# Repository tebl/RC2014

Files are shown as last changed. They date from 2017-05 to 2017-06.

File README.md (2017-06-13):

# RC2014

I've been spending a lot of time lately working on extensions to the excellent RC2014 machine, check out the official web page at [http://rc2014.co.uk](http://rc2014.co.uk) if you're not familiar with it. Short story; it's a Z80-based homecomputer that you can build yourself using a soldering iron, lots of time and severely burned fingers. A lot of fun indeed!

I've been documenting the build process of the various components on my blog at [https://hvetebolle.blogspot.no/p/rc2014.html](https://hvetebolle.blogspot.no/p/rc2014.html), but take note that it's in my native language of Norwegian so it might not register as readable for most people.

## Modules

I'll be making a subfolder for each of the modules I've been working on, most of the files will be in KiCad format so you'll need this open source application installed if you intend to work with the schematics. For the most part I will include the necessary Gerber files (for PCB production) in each modules export folder, the schematic in PDF-format will also probably be included - also, in the export folder.

* [RC2014 IDE ATA adapter](https://github.com/tebl/RC2014/tree/master/RC2014%20IDE)
* [RC2014 Pageable RAM](https://github.com/tebl/RC2014/tree/master/RC2014%20RAM)
* [RC2014 Tandy Sound Card](https://github.com/tebl/RC2014/tree/master/RC2014%20Tandy%20Sound%20Card)

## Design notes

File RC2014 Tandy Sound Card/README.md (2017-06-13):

# RC2014 Tandy Sound Card

This is a sound card for the RC2014 that I've been tinkering with, it's based on the SN76489N chip so it should be something akin to the original Tandy Sound Card. Not that I actually had one of those mind you, I was lucky enough to have a computer in the early 90s and that was years before I managed to get a hold of my first used sound card (Creative Soundblaster 8-bit). Anyways, I digress...

# Schematic
The supplied KiCad files should be sufficient as both a schematic and as a starting point for ordering PCBs (basically you could just zip the contents of the export folder and upload that on a fabrication site), the schematic is also available in [PDF-format](https://github.com/tebl/RC2014/raw/master/RC2014%20Tandy%20Sound%20Card/export/RC2014%20Tandy%20Sound%20Card.pdf) so that you can refer to it while troubleshooting bad solder joints.

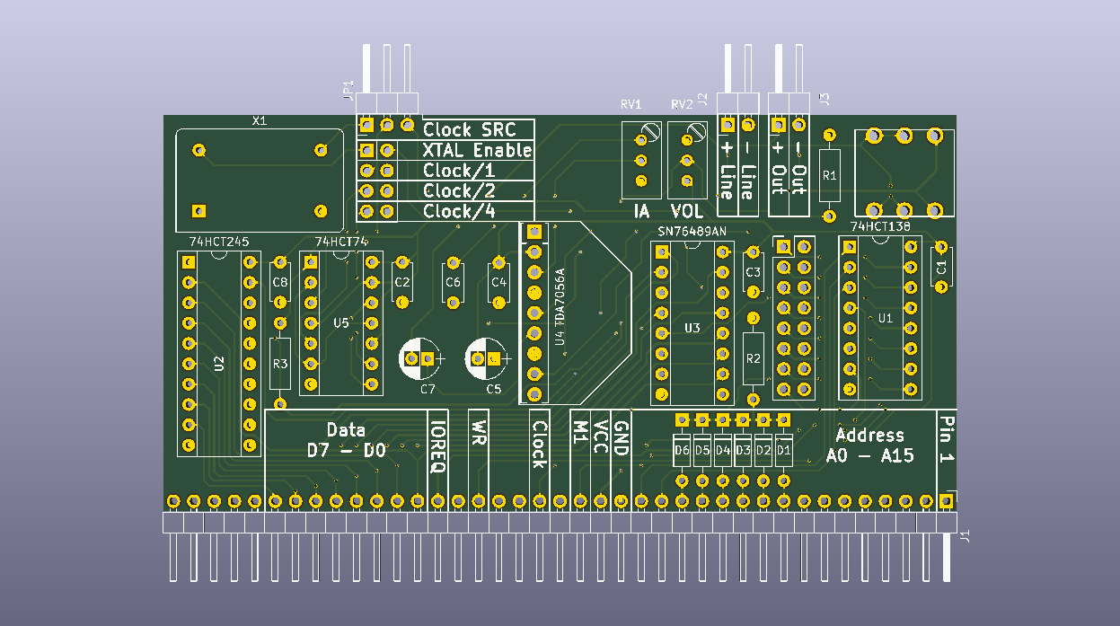
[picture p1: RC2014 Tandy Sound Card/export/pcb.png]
PCB Preview


# BOM
This is the part list as it stands now, having not yet received nor assembled the first version of this card so some changes will probably happen. Note that since this includes a lot of circuitry dealing with amplifying the signal, some parts of this may be left out if they are not needed. Jack socket may be omitted if you only want to attach a simple speaker to it using the one of the two speaker outputs J2 and J3 (with amplification). Crystal may be omitted, instead you can use the system clock with the clock divider to get this below SN76489AN max frequency (4 Mhz) - with a stock RC2014 you would atleast need to set J6 to divide it in half.

| Reference | Item | Count |
| --- | --- | ----- |
| PCB | Fabricate yourself using Gerber files | 1 |
| U1 | 74HCT138 DIP | 1 |
| U2 | 74HCT245 DIP | 1 |
| U3 | SN76489AN DIP | 1 |
| U4 | TDA7056A SIP (mono amplifier) | 1 |
| U5 | 74HCT74 DIP | 1 |
| RV1 - RV2 | Adjustable resistor, 10k | 2 |
| R1 | 1k resistor | 1 |
| R2, R3 | 10k resistor | 2 |
| X1 | TTL Oscillator, full can (DIP 14) | 1 |
| C1-C4, C8 | 100nF ceramic capacitor | 1 |
| C5 | 220uF electrolytic capacitor | 1 |
| C6 | 470nF ceramic capacitor | 1 |
| C7 | 470uF electrolytic capacitor | 1 |
| J1 | Single row, 39p right angle connector | 1 |
| J2, J3 | Single row, 2p right angle connector  | 2 |
| J4 | Dual row, 2x08 connector | 1 |
| J5 | FCR1295 3.5mm Jack Socket | 1 |
| J6 | Dual row, 2x04 connector | 1 |
| D1 - D6 | 1N4848 diode | 6 |

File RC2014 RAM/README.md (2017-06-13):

# RC2014 RAM

This is a customized RAM module that enables you to page the module in and out, similar to the 64K module available. The difference here is that I'm only using one RAM chip per card. The reason for this is simple, PCB manufacturers don't seem to want to make a single PCB so this way I can use more of them at once!

The PCB places the paging pin on one of the spare pins of the backplane, that way I don't have to run any wires between the cards.

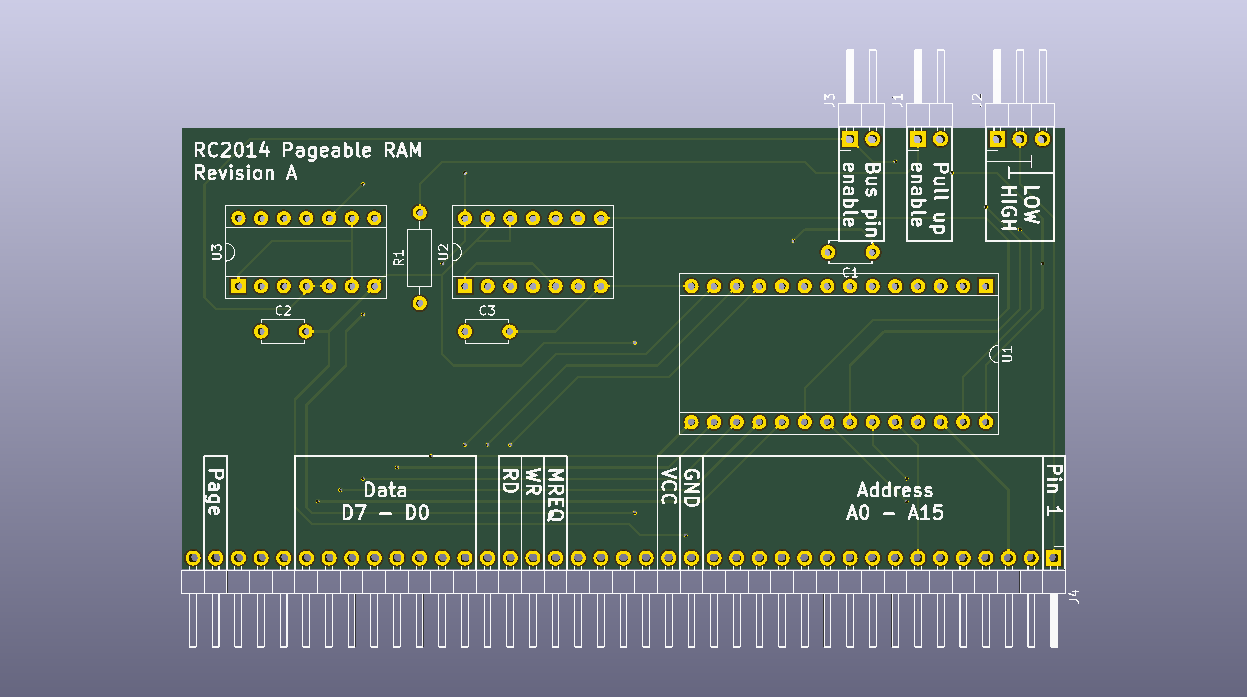
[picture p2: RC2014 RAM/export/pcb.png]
RAM PCB


# Schematic
The supplied KiCad files should be sufficient as both a schematic and as a starting point for ordering PCBs (basically you could just zip the contents of the export folder and upload that on a fabrication site), the schematic is also available in [PDF-format](https://github.com/tebl/RC2014/raw/master/RC2014%20RAM/export/RC2014%20RAM.pdf) so that you can refer to it while troubleshooting bad solder joints.

# BOM
| Reference | Item | Count |
| --- | --- | ----- |
| PCB | Fabricate yourself using Gerber files | 1 |
| U1 | 62256 32k * bit Static RAM | 1 |
| U2 | 74HCT32 DIP | 1 |
| U3 | 74HCT00 DIP | 1 |
| J2 | Single row, 3p right angle connector  | 1 |
| J1, J3 | Single row, 2p right angle connector  | 2 |
| J4 | Single row, 39p right angle connector | 1 |
| C1 - C3 | Ceramic capacitor, disc 100nF | 3 |

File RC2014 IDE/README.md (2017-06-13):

# RC2014 IDE ATA adapter

This is an IDE ATA adapter I've been working so that I can avoid having to learn how to solder surface mount components like the one used on the officialy available Compact Flash module. This gives you a standard ATA IDE connector that you can use for anything that still supports 8-bit IDE, where this relates to the Compact Flash module is that you can use it to connect up to a cheap Compact Flash to IDE adapter. See Scripts for a sample Basic-script that can be used to test the adapter.

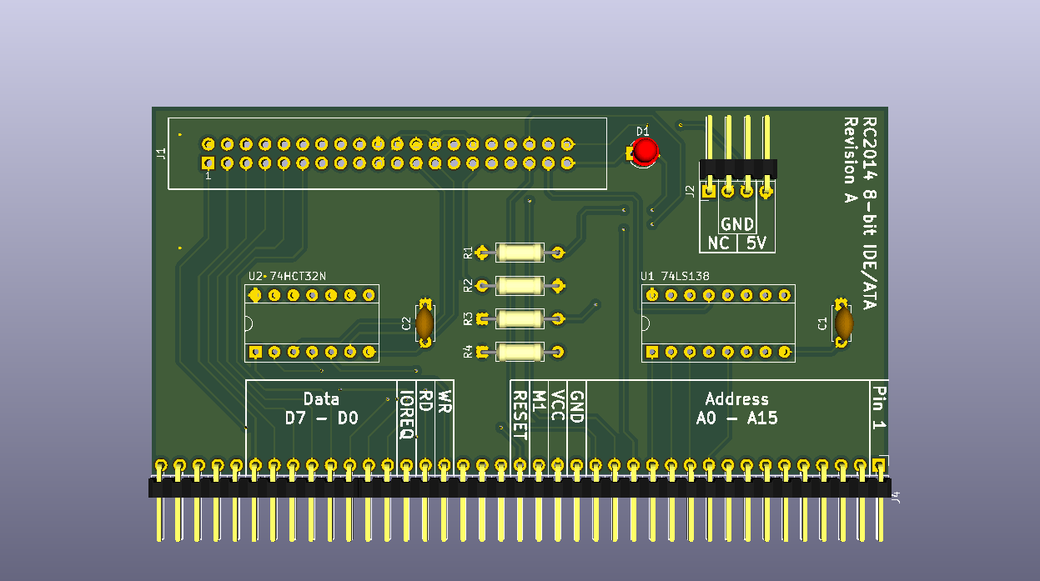
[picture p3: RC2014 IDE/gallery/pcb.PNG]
IDE PCB


Wired up

# Schematic
The supplied KiCad files should be sufficient as both a schematic and as a starting point for ordering PCBs (basically you could just zip the contents of the export folder and upload that on a fabrication site), the schematic is also available in [PDF-format](https://github.com/tebl/RC2014/raw/master/RC2014%20IDE/export/RC2014%20IDE.pdf) so that you can refer to it while troubleshooting bad solder joints.

# BOM
| Reference | Item | Count |
| --- | --- | ----- |
| PCB | Fabricate yourself using Gerber files | 1 |
| R1 - R3 | 1k resistor | 3 |
| R4 | 330 resistor | 1 |
| J1 | Dual row, 20p right angle connector | 1 |
| J2 | Single row, 4p right angle connector  | 1 |
| J4 | Single row, 39p right angle connector | 1 |
| C1 | Ceramic capacitor, disc 100nF | 1 |
| | 40 pin IDE cable (gray type) | 1 |
| | CF to IDE ATA adapter | 1 |

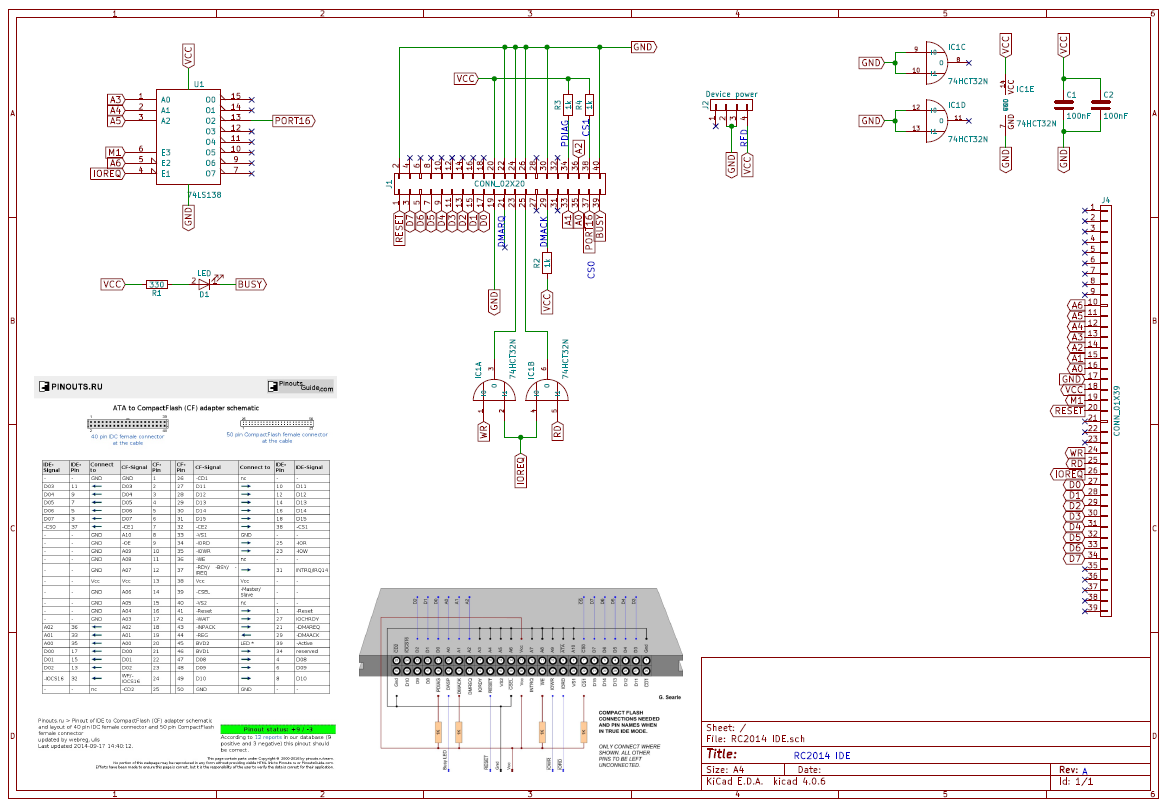
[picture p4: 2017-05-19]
RC2014 IDE/gallery/schematic (updated).PNG

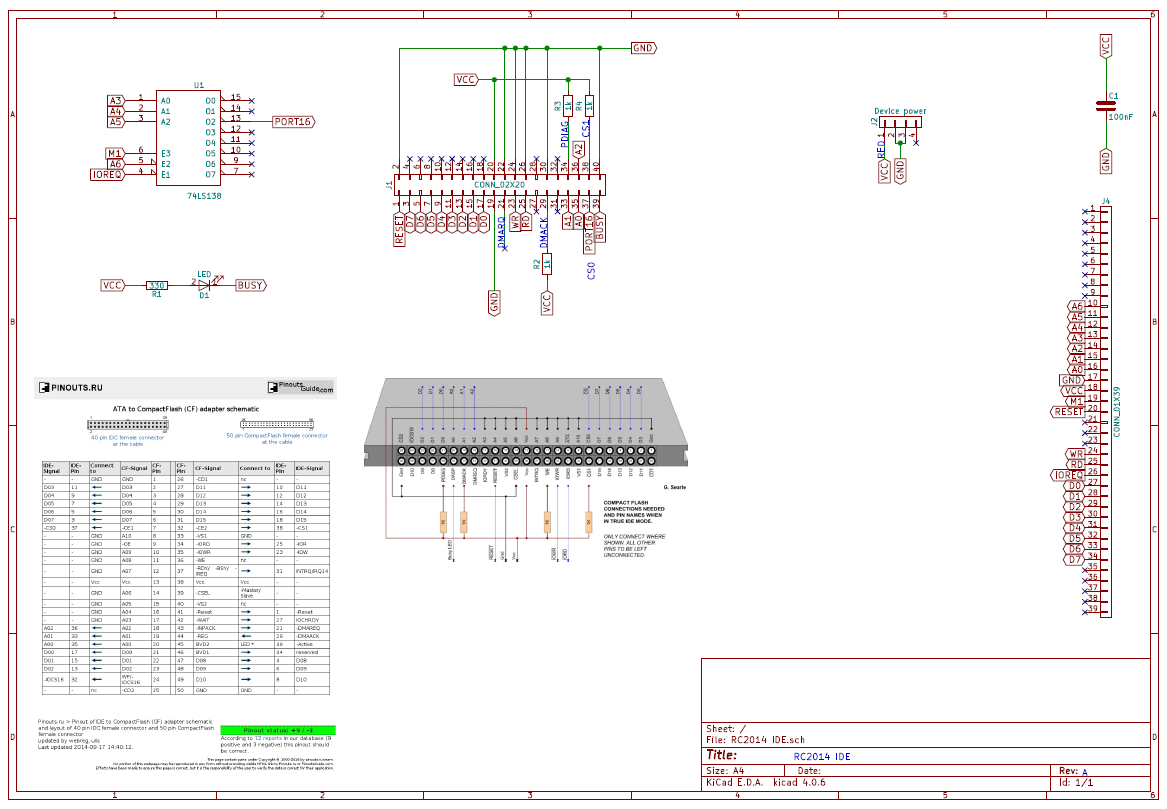
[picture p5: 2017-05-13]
RC2014 IDE/gallery/schematic.PNG

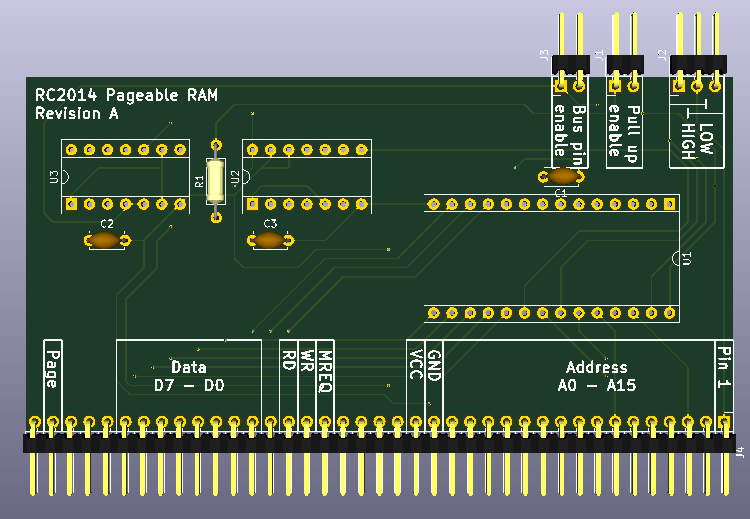
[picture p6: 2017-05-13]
RC2014 RAM/gallery/pcb.PNG

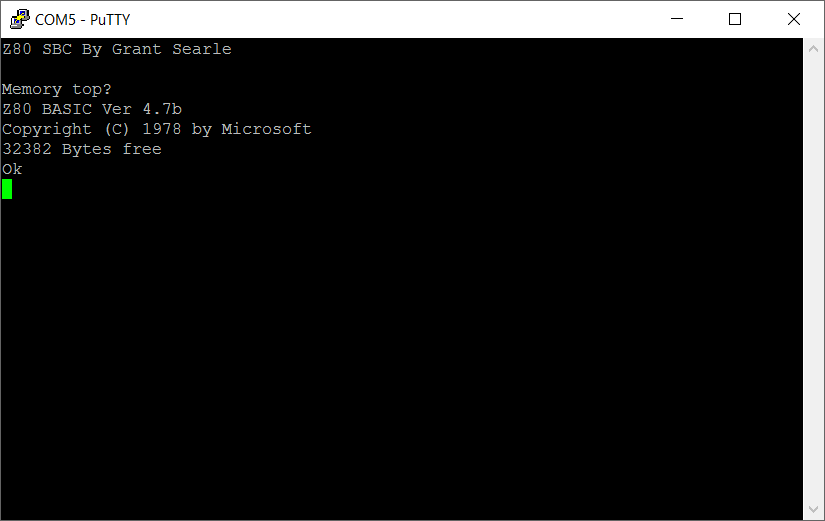
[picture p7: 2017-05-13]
Gallery/rc2014_ok.PNG

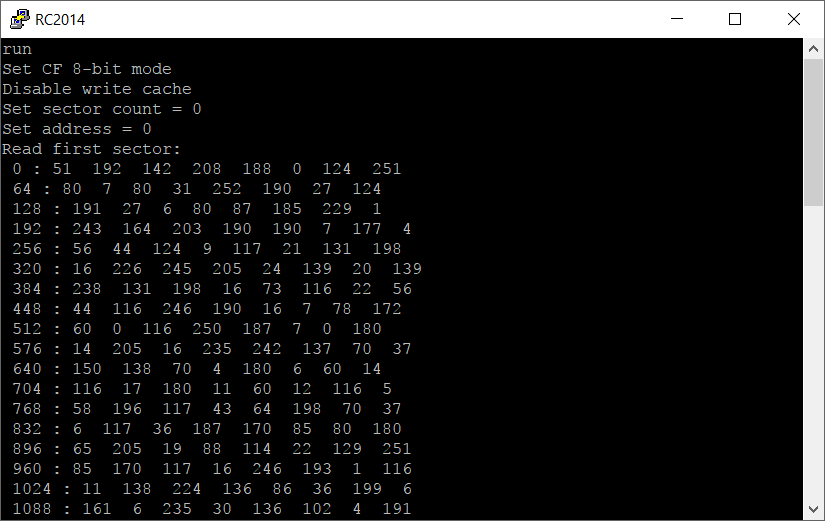
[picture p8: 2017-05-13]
RC2014 IDE/gallery/CF Sandisk Basic.PNG

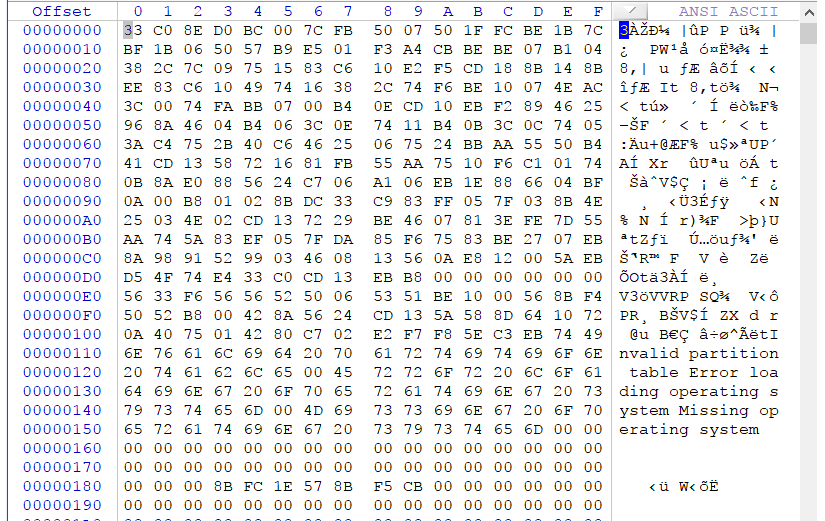
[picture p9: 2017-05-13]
RC2014 IDE/gallery/CF Sandisk.PNG

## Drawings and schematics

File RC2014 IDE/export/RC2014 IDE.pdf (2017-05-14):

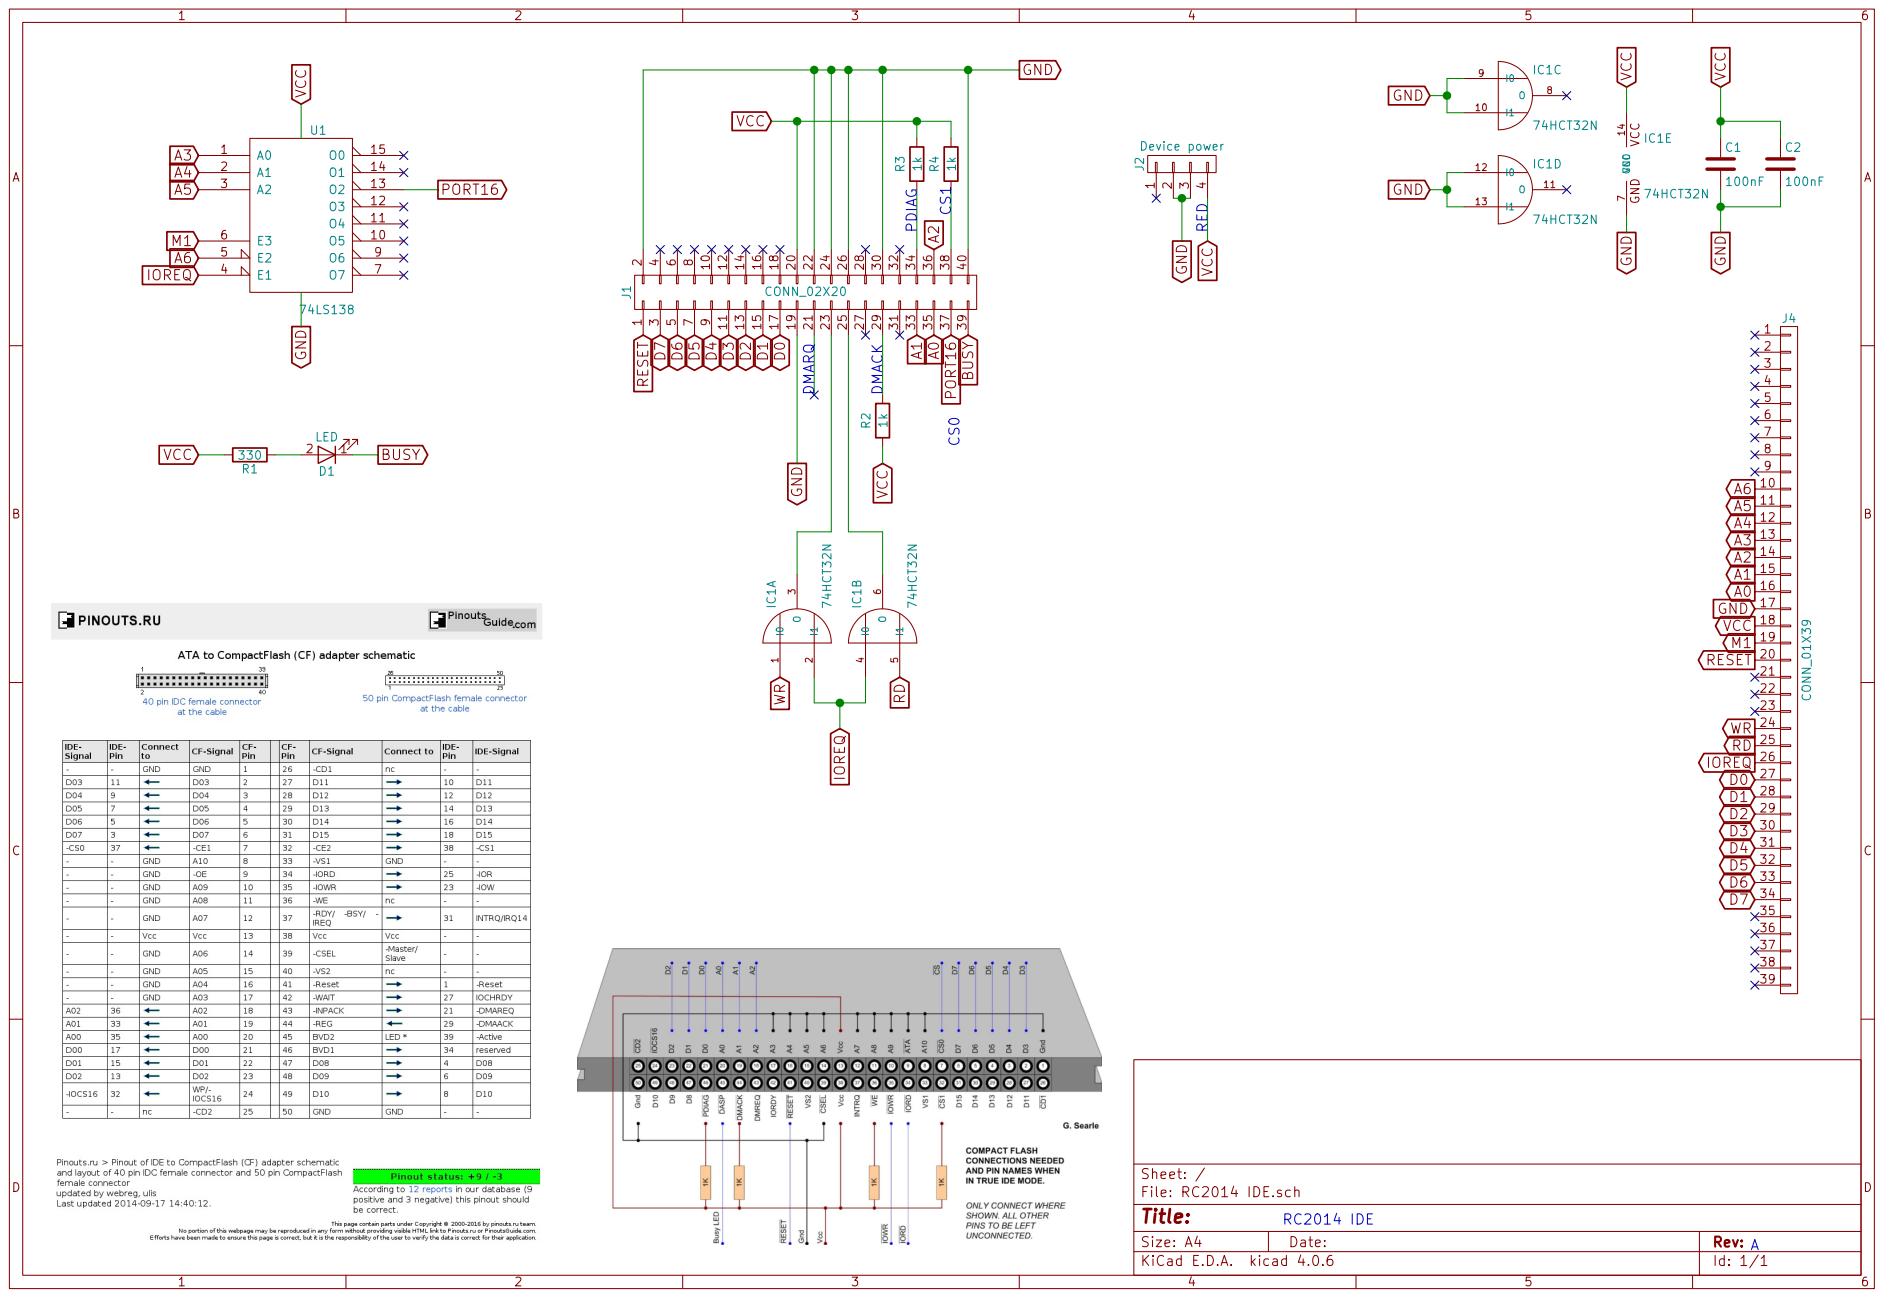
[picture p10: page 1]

Device power GND RED

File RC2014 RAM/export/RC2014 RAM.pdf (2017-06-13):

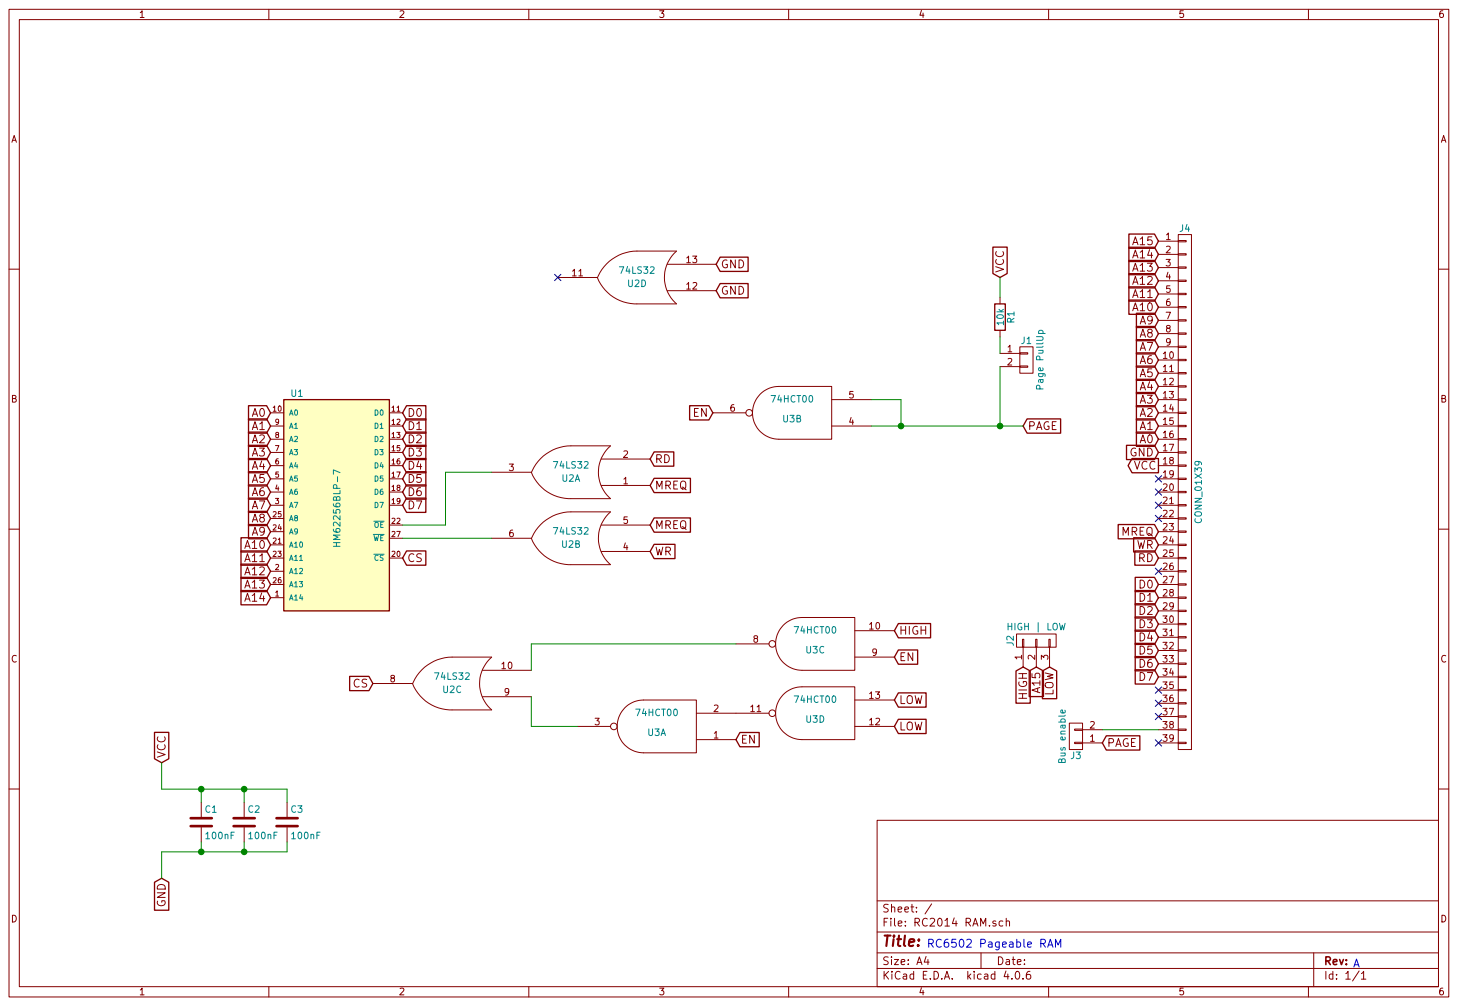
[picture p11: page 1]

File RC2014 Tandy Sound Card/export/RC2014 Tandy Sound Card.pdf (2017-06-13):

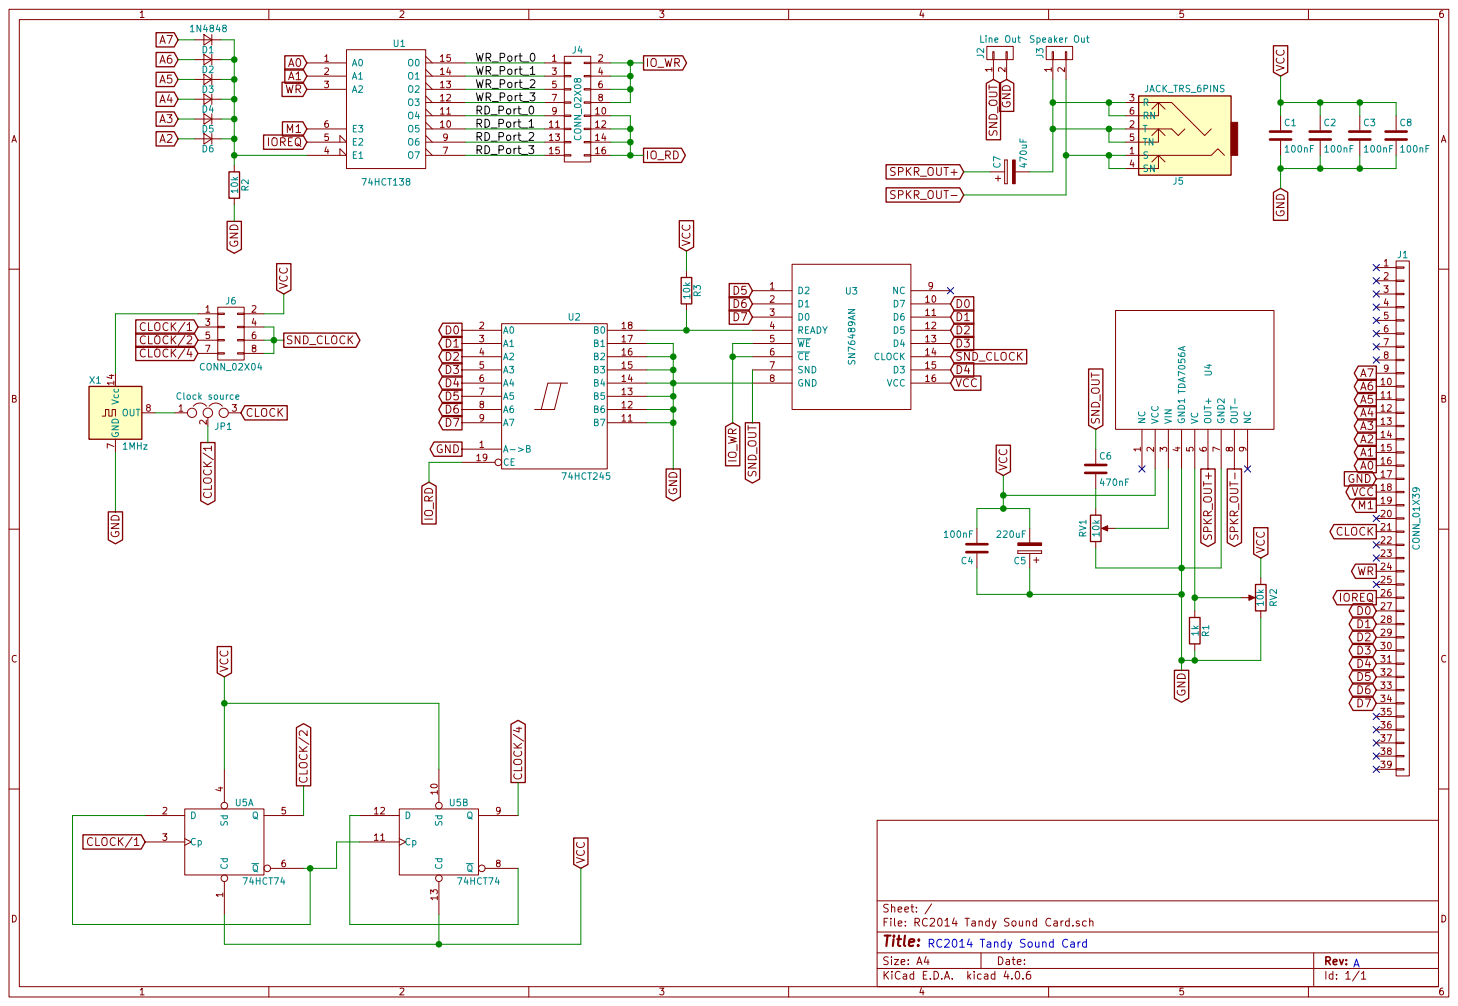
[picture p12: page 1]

RD_Port_1 11 | 12
RD_Port_2 13 | 14
RD_Port_3 15 | 16

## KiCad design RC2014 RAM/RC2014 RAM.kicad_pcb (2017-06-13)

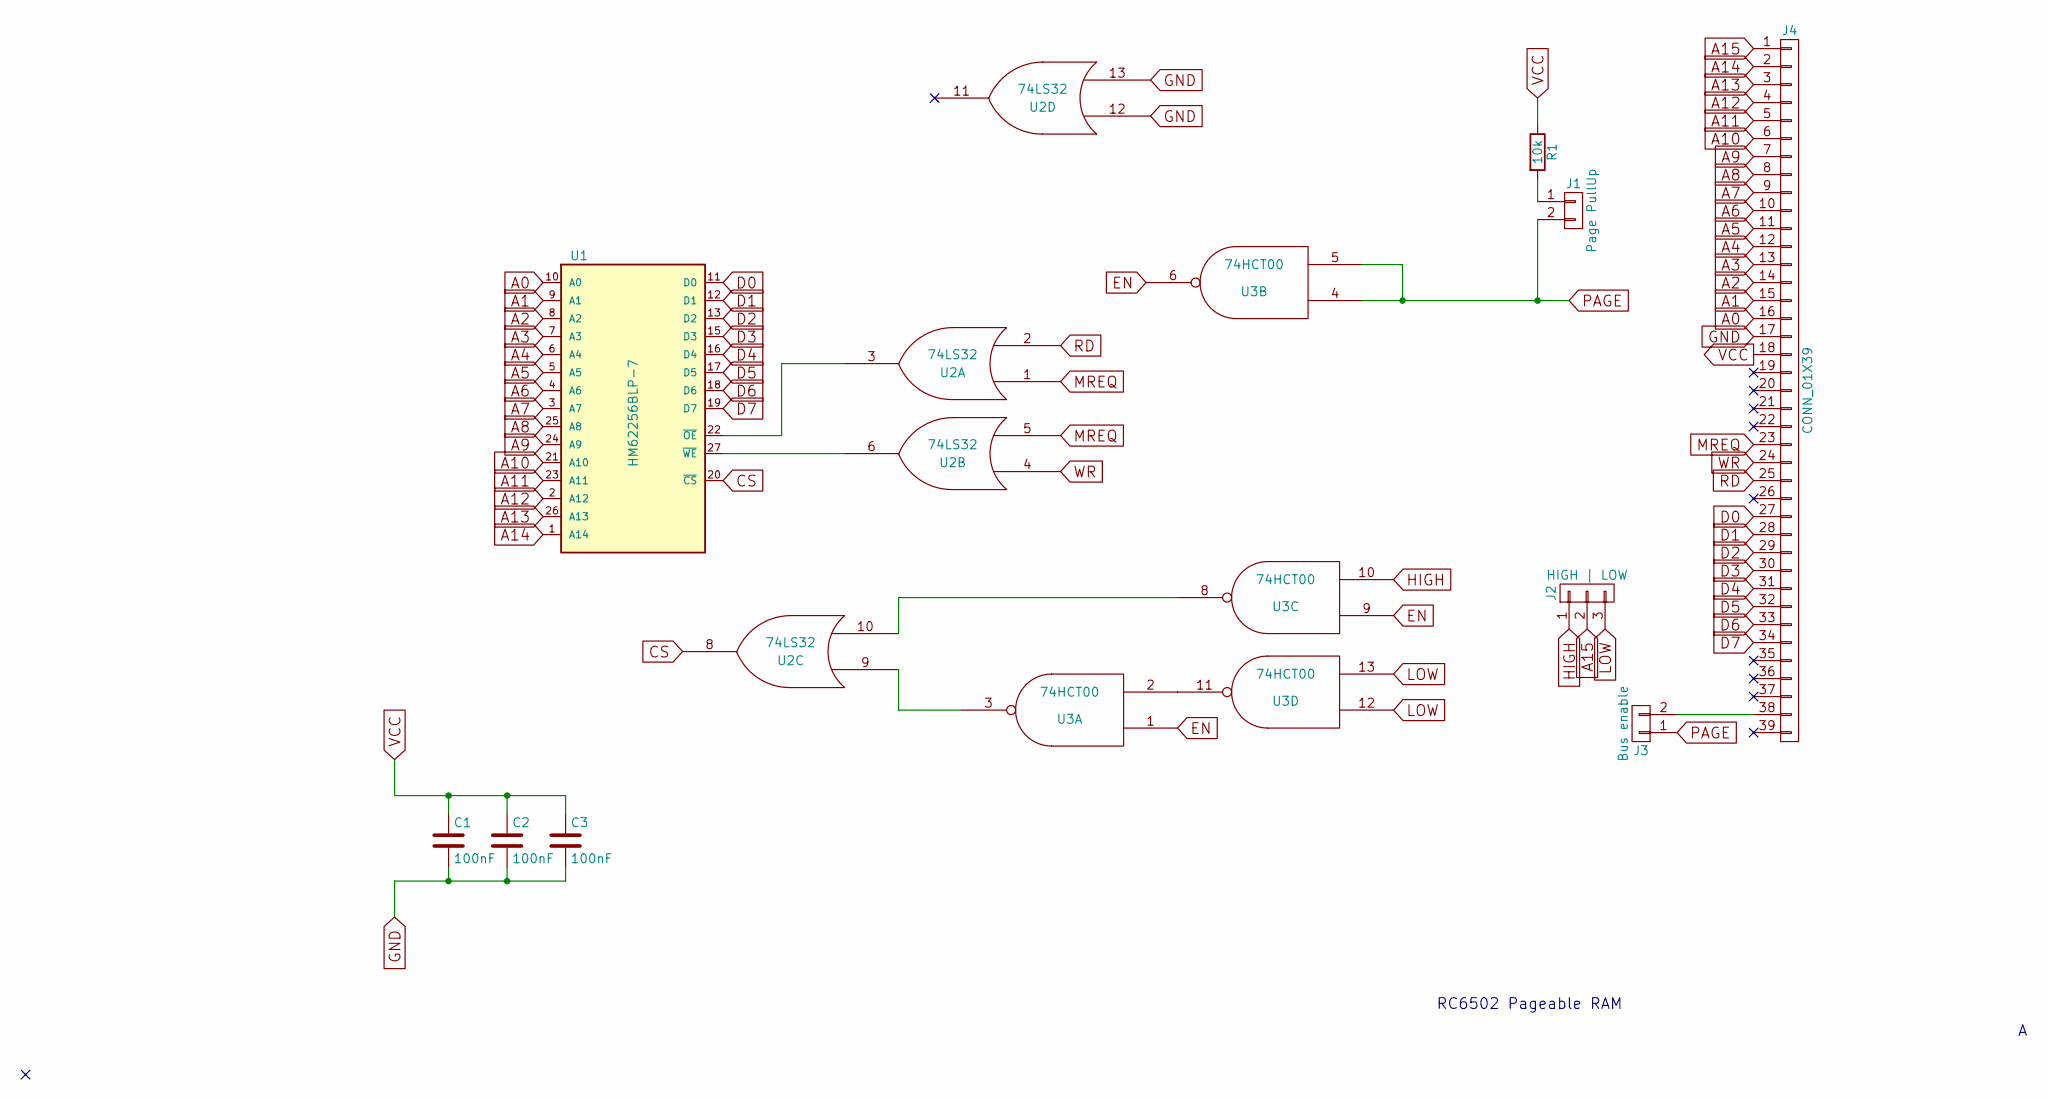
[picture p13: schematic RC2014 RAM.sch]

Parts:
C1, C2, C3: 100nF; C_Disc_D4.7mm_W2.5mm_P5.00mm
J1: Page PullUp; Pin_Header_Angled_1x02_Pitch2.54mm
J2: HIGH | LOW; Pin_Header_Angled_1x03_Pitch2.54mm
J3: Bus enable; Pin_Header_Angled_1x02_Pitch2.54mm
J4: CONN_01X39; Pin_Header_Angled_1x39_Pitch2.54mm
R1: 10k; R_Axial_DIN0207_L6.3mm_D2.5mm_P10.16mm_Horizontal
U1: HM62256BLP-7; DIP-28_W15.24mm_Socket
U2: 74LS32; DIP-14_W7.62mm_Socket
U3: 74HCT00; DIP-14_W7.62mm_Socket

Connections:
A0: J4.16, U1.10 (A0)
A1: J4.15, U1.9 (A1)
A2: J4.14, U1.8 (A2)
A3: J4.13, U1.7 (A3)
A4: J4.12, U1.6 (A4)
A5: J4.11, U1.5 (A5)
A6: J4.10, U1.4 (A6)
A7: J4.9, U1.3 (A7)
A8: J4.8, U1.25 (A8)
A9: J4.7, U1.24 (A9)
A10: J4.6, U1.21 (A10)
A11: J4.5, U1.23 (A11)
A12: J4.4, U1.2 (A12)
A13: J4.3, U1.26 (A13)
A14: J4.2, U1.1 (A14)
A15: J2.2, J4.1
CS: U1.20 (~CS), U2.8
D0: J4.27, U1.11 (D0)
D1: J4.28, U1.12 (D1)
D2: J4.29, U1.13 (D2)
D3: J4.30, U1.15 (D3)
D4: J4.31, U1.16 (D4)
D5: J4.32, U1.17 (D5)
D6: J4.33, U1.18 (D6)
D7: J4.34, U1.19 (D7)
EN: U3.1, U3.6, U3.9
GND: C1.2, C2.2, C3.2, J4.17, U1.14 (GND), U2.7 (GND), U2.12, U2.13, U3.7 (GND)
HIGH: J2.1, U3.10
LOW: J2.3, U3.12, U3.13
MREQ: J4.23, U2.1, U2.5
unnamed: J1.1, R1.2
unnamed: J3.2, J4.38
unnamed: U1.22 (~OE), U2.3
unnamed: U1.27 (~WE), U2.6
unnamed: U2.9, U3.3
unnamed: U2.10, U3.8
unnamed: U3.2, U3.11
PAGE: J1.2, J3.1, U3.4, U3.5
RD: J4.25, U2.2
VCC: C1.1, C2.1, C3.1, J4.18, R1.1, U1.28 (VCC), U2.14 (VCC), U3.14 (VCC)
WR: J4.24, U2.4

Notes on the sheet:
RC6502 Pageable RAM

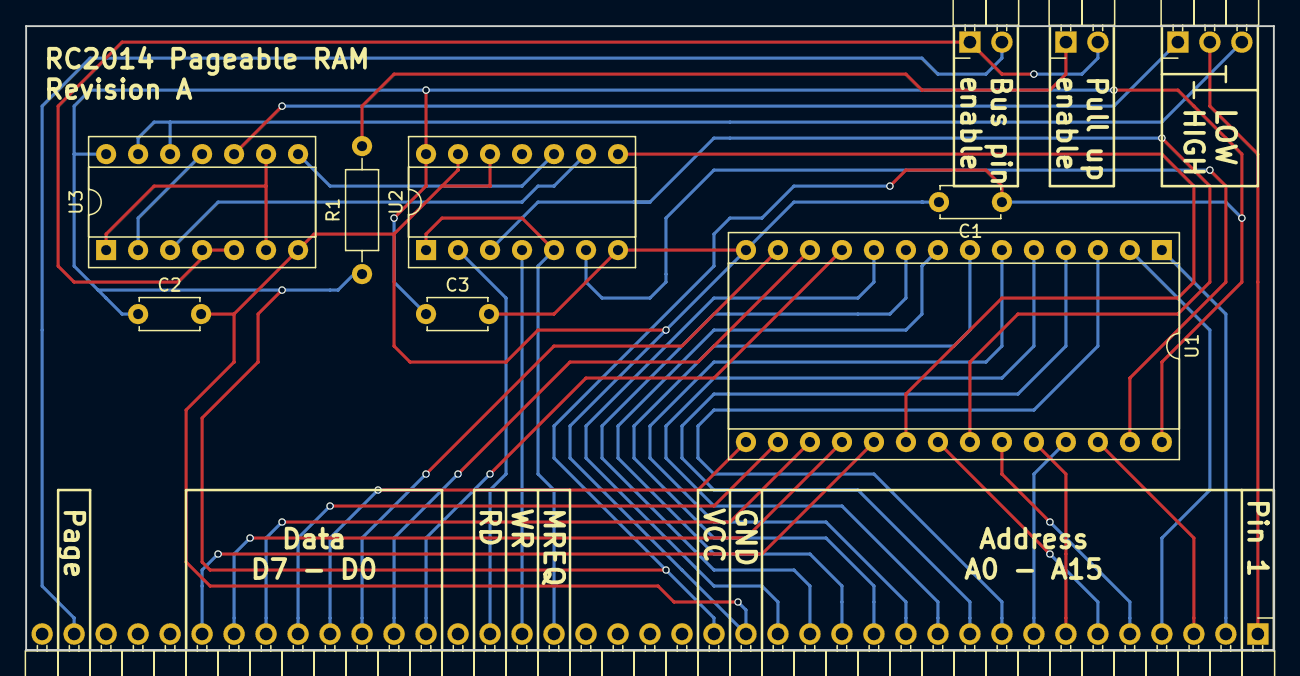
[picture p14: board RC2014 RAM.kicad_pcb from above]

Board: 2 copper layers, 99.1 x 49.5 mm, 11 parts (0 on the bottom side), 41 nets.

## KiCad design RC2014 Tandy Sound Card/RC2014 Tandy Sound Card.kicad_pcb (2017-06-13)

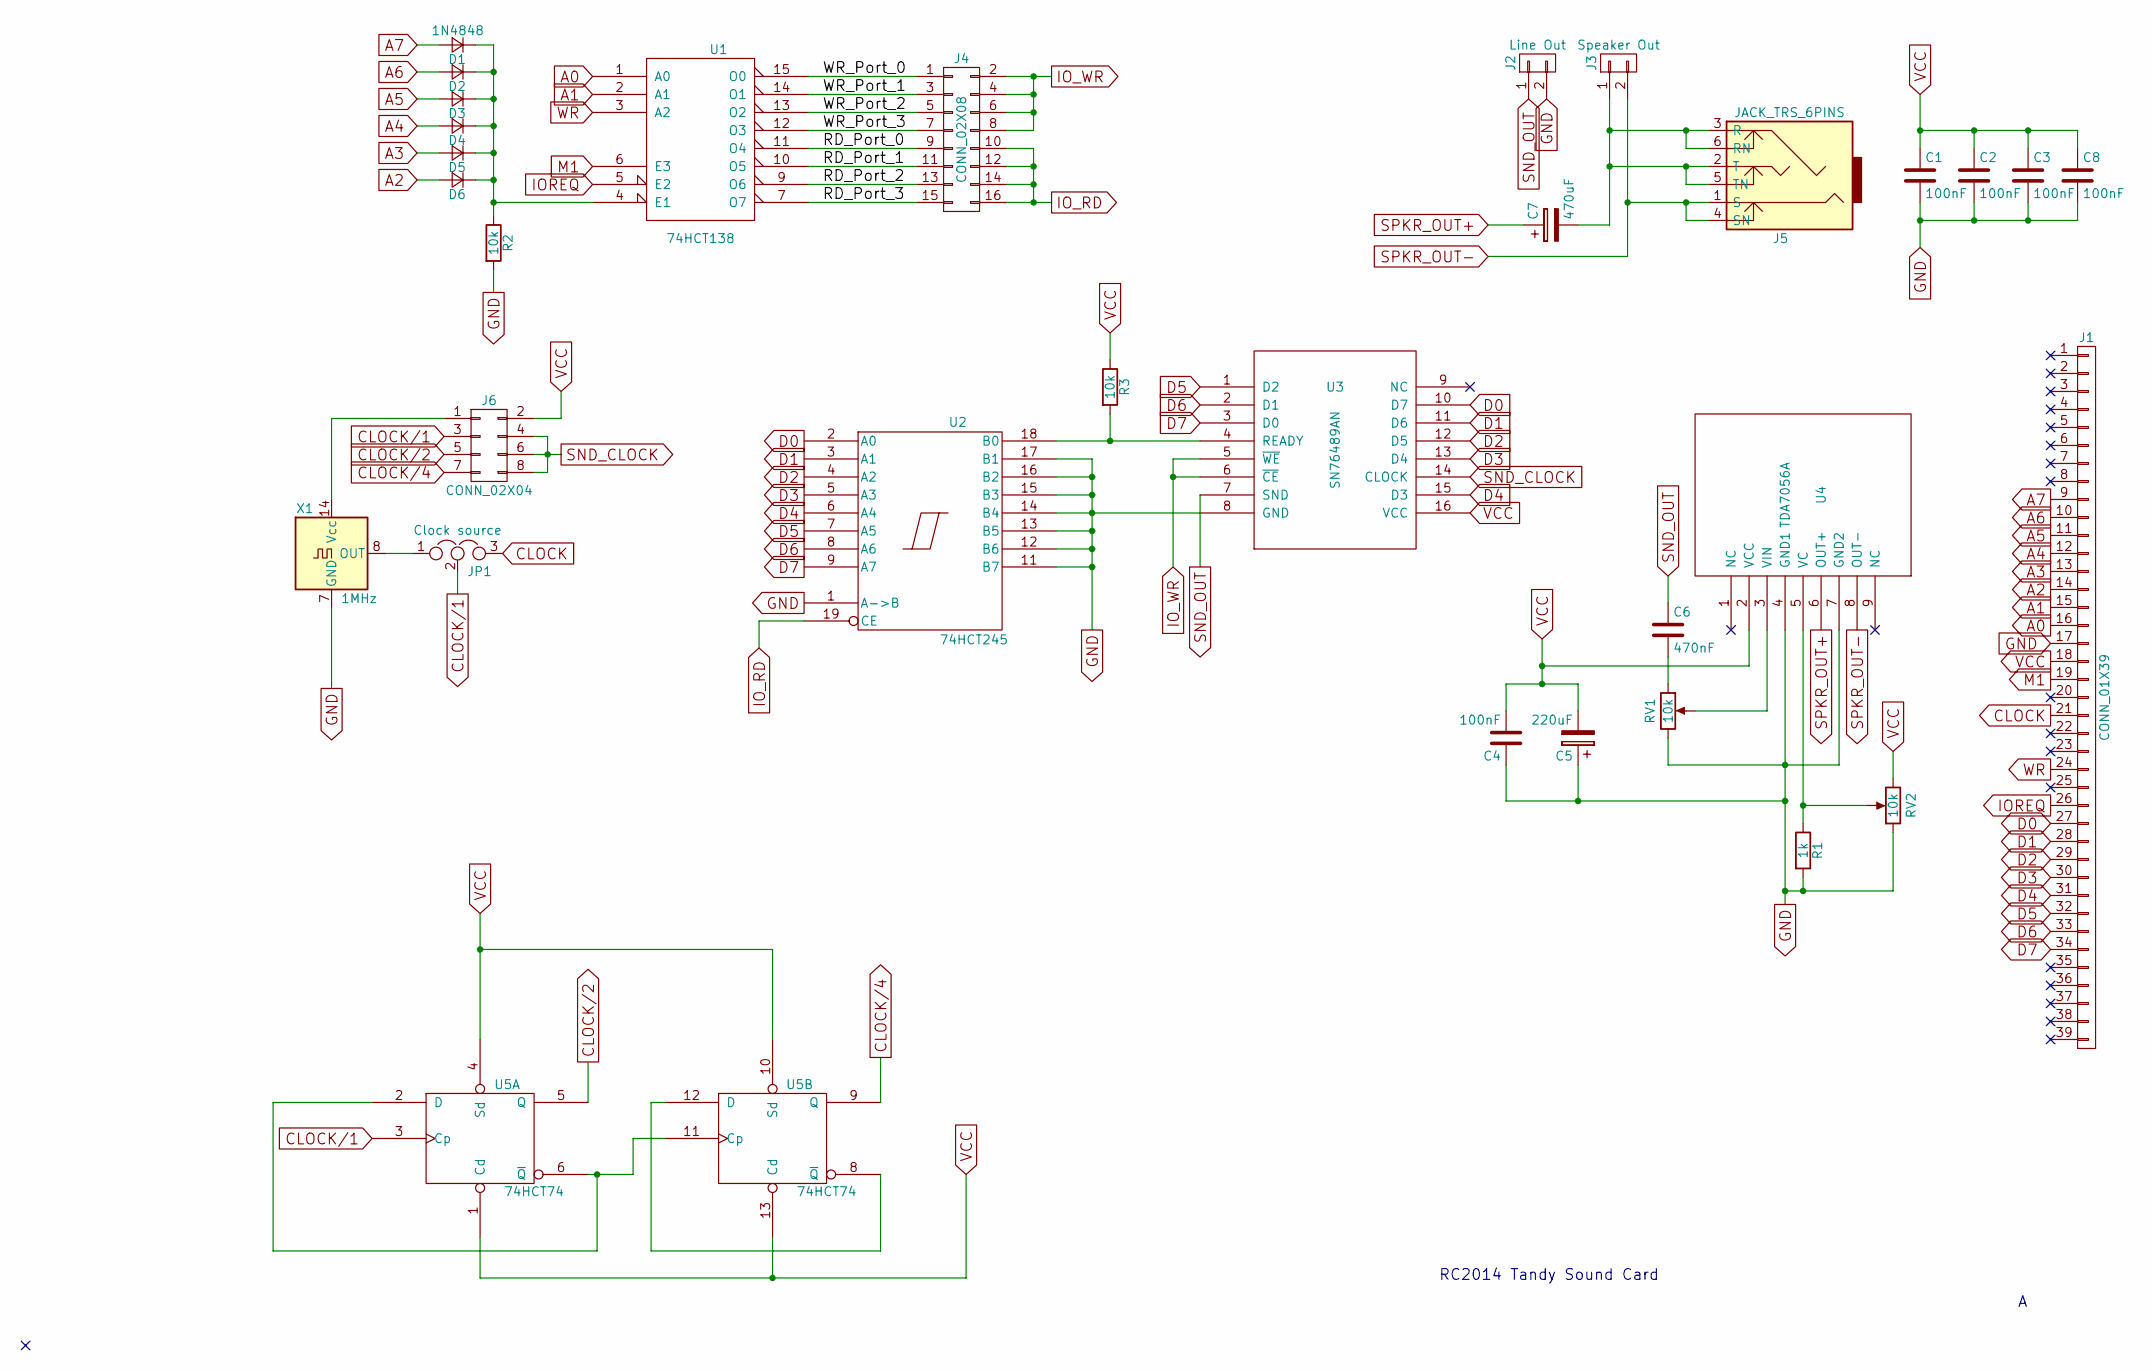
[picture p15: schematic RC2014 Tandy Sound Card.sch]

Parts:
C1, C2, C3, C4, C8: 100nF; C_Disc_D4.7mm_W2.5mm_P5.00mm
C5: 220uF; CP_Radial_D5.0mm_P2.00mm
C6: 470nF; C_Disc_D4.7mm_W2.5mm_P5.00mm
C7: 470uF; CP_Radial_D5.0mm_P2.00mm
D1, D2, D3, D4, D5, D6: 1N4848; D_DO-35_SOD27_P7.62mm_Horizontal
J1: CONN_01X39; Pin_Header_Angled_1x39_Pitch2.54mm
J2: Line Out; Pin_Header_Angled_1x02_Pitch2.54mm
J3: Speaker Out; Pin_Header_Angled_1x02_Pitch2.54mm
J4: CONN_02X08; Pin_Header_Straight_2x08_Pitch2.54mm
J5: JACK_TRS_6PINS; cliff_fcr1295_socket
J6: CONN_02X04; Pin_Header_Straight_2x04_Pitch2.54mm
JP1: Clock source; Pin_Header_Angled_1x03_Pitch2.54mm
R1: 1k; R_Axial_DIN0207_L6.3mm_D2.5mm_P10.16mm_Horizontal
R2, R3: 10k; R_Axial_DIN0207_L6.3mm_D2.5mm_P10.16mm_Horizontal
RV1, RV2: 10k; Potentiometer_Trimmer_Bourns_3296W
U1: 74HCT138; DIP-16_W7.62mm_Socket
U2: 74HCT245; DIP-20_W7.62mm_Socket
U3: SN76489AN; DIP-16_W7.62mm_Socket
U4: TDA7056A; SIP9_Housing
U5: 74HCT74; DIP-14_W7.62mm_Socket
X1: 1MHz; Oscillator_DIP-14

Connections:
/RD_Port_0: J4.9, U1.11 (O4)
/RD_Port_1: J4.11, U1.10 (O5)
/RD_Port_2: J4.13, U1.9 (O6)
/RD_Port_3: J4.15, U1.7 (O7)
/WR_Port_0: J4.1, U1.15 (O0)
/WR_Port_1: J4.3, U1.14 (O1)
/WR_Port_2: J4.5, U1.13 (O2)
/WR_Port_3: J4.7, U1.12 (O3)
A0: J1.16, U1.1 (A0)
A1: J1.15, U1.2 (A1)
A2: D6.2 (A), J1.14
A3: D5.2 (A), J1.13
A4: D4.2 (A), J1.12
A5: D3.2 (A), J1.11
A6: D2.2 (A), J1.10
A7: D1.2 (A), J1.9
CLOCK: J1.21, JP1.3
CLOCK/1: J6.3, JP1.2, U5.3 (Cp)
CLOCK/2: J6.5, U5.5 (Q)
CLOCK/4: J6.7, U5.9 (Q)
D0: J1.27, U2.2 (A0), U3.10 (D7)
D1: J1.28, U2.3 (A1), U3.11 (D6)
D2: J1.29, U2.4 (A2), U3.12 (D5)
D3: J1.30, U2.5 (A3), U3.13 (D4)
D4: J1.31, U2.6 (A4), U3.15 (D3)
D5: J1.32, U2.7 (A5), U3.1 (D2)
D6: J1.33, U2.8 (A6), U3.2 (D1)
D7: J1.34, U2.9 (A7), U3.3 (D0)
GND: C1.2, C2.2, C3.2, C4.1, C5.1, C8.2, J1.17, J2.2, R1.2, R2.2, RV1.3, RV2.1, U1.8 (GND), U2.1 (A->B), U2.10 (GND), U2.11 (B7), U2.12 (B6), U2.13 (B5), U2.14 (B4), U2.15 (B3), U2.16 (B2), U2.17 (B1), U3.8 (GND), U4.4 (GND1), U4.7 (GND2), U5.7 (GND), X1.7 (GND)
IOREQ: J1.26, U1.5 (E2)
IO_RD: J4.10, J4.12, J4.14, J4.16, U2.19 (CE)
IO_WR: J4.2, J4.4, J4.6, J4.8, U3.5 (~WE), U3.6 (~CE)
M1: J1.19, U1.6 (E3)
unnamed: C6.2, RV1.1
unnamed: C7.2, J3.1, J5.2 (T), J5.3 (R), J5.5 (TN), J5.6 (RN)
unnamed: D1.1 (K), D2.1 (K), D3.1 (K), D4.1 (K), D5.1 (K), D6.1 (K), R2.1, U1.4 (E1)
unnamed: J6.1, X1.14 (Vcc)
unnamed: JP1.1, X1.8 (OUT)
unnamed: R1.1, RV2.2, U4.5 (VC)
unnamed: R3.2, U2.18 (B0), U3.4 (READY)
unnamed: RV1.2, U4.3 (VIN)
unnamed: U5.2 (D), U5.6 (~Q), U5.11 (Cp)
unnamed: U5.8 (~Q), U5.12 (D)
SND_CLOCK: J6.4, J6.6, J6.8, U3.14 (CLOCK)
SND_OUT: C6.1, J2.1, U3.7 (SND)
SPKR_OUT+: C7.1, U4.6 (OUT+)
SPKR_OUT-: J3.2, J5.1 (S), J5.4 (SN), U4.8 (OUT-)
VCC: C1.1, C2.1, C3.1, C4.2, C5.2, C8.1, J1.18, J6.2, R3.1, RV2.3, U1.16 (VCC), U2.20 (VCC), U3.16 (VCC), U4.2 (VCC), U5.1 (Cd), U5.4 (Sd), U5.10 (Sd), U5.13 (Cd), U5.14 (VCC)
WR: J1.24, U1.3 (A2)

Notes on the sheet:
RC2014 Tandy Sound Card

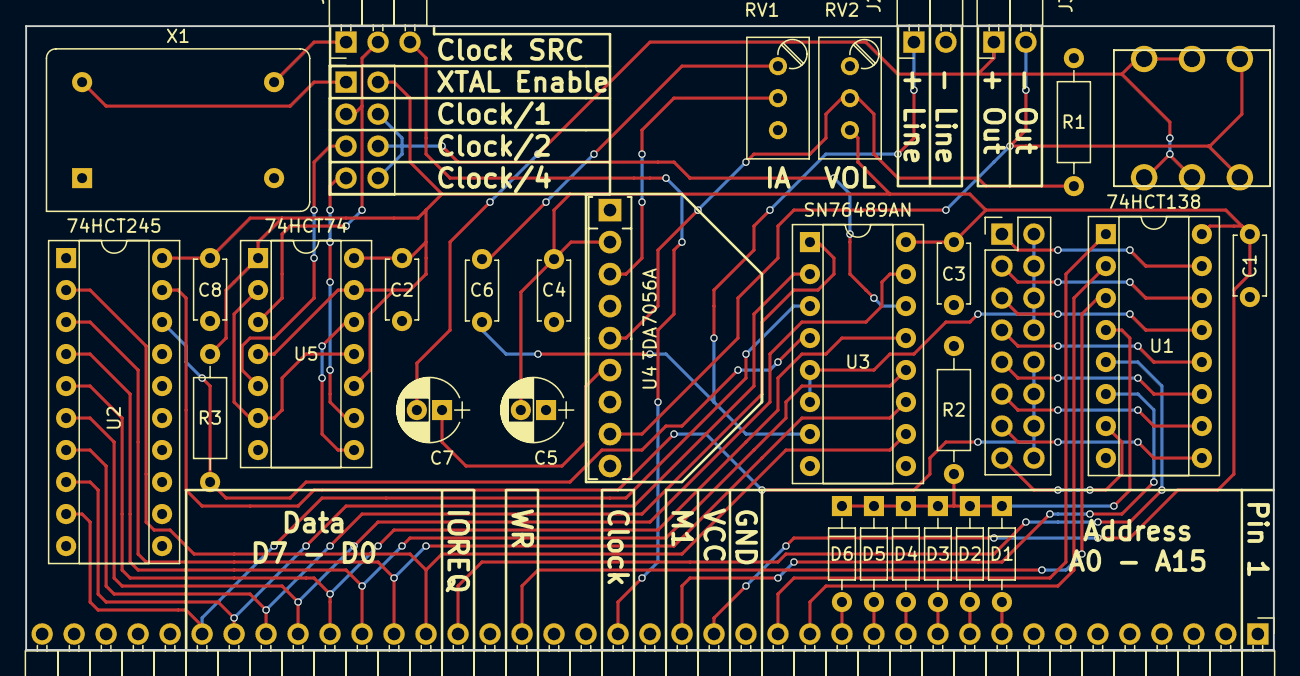
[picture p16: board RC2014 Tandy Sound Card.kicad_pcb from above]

Board: 2 copper layers, 99.1 x 49.5 mm, 32 parts (0 on the bottom side), 49 nets.

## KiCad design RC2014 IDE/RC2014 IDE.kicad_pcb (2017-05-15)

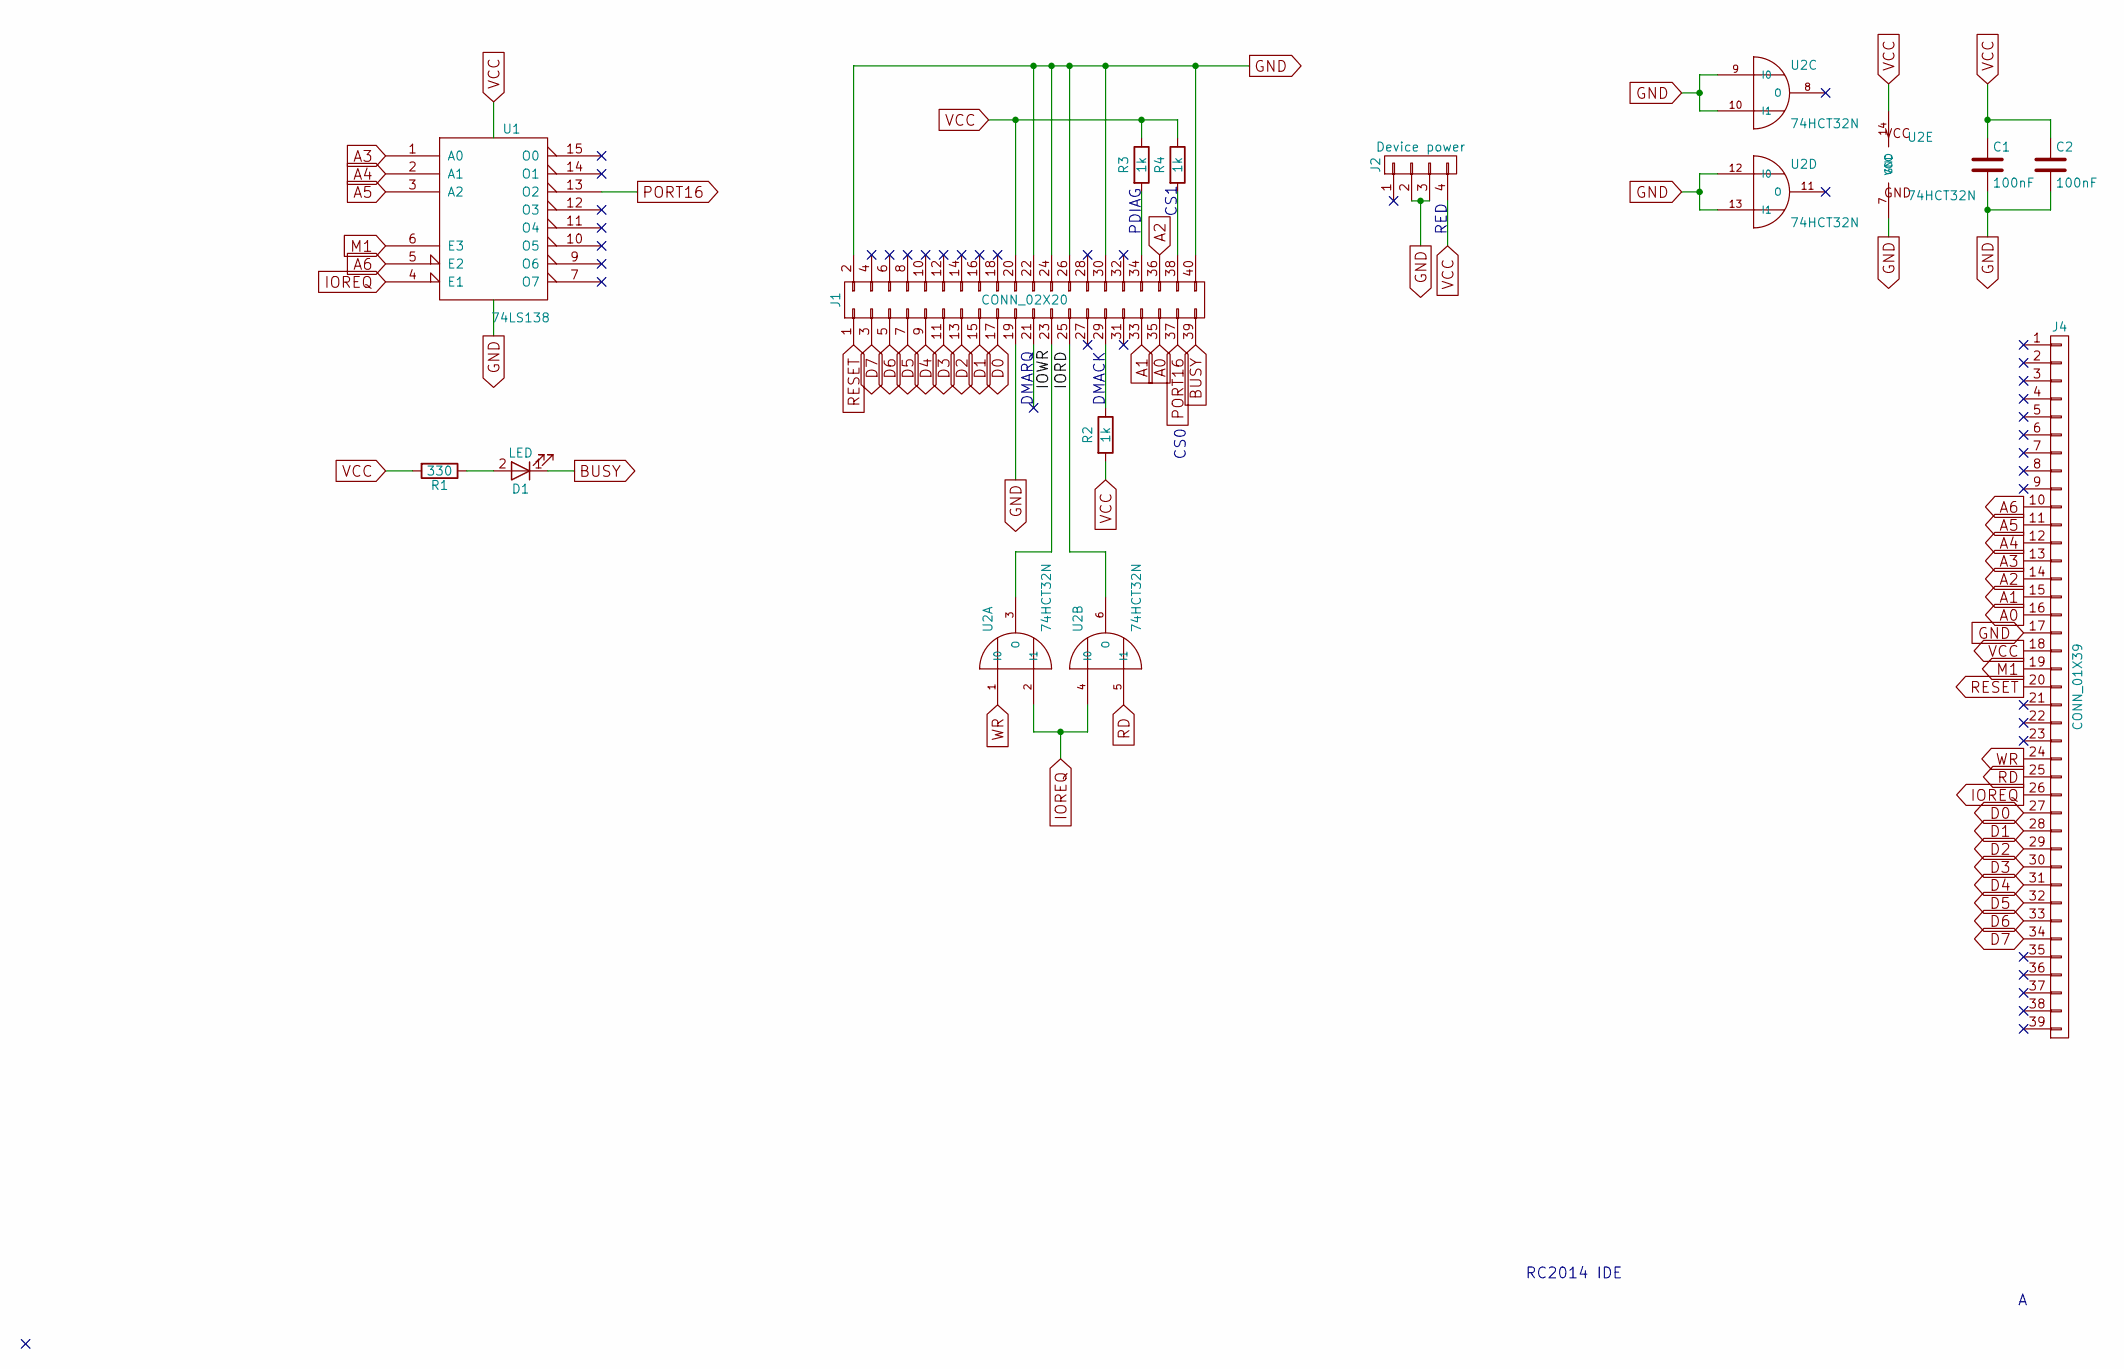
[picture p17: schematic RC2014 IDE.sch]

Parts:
C1, C2: 100nF; C_Disc_D4.7mm_W2.5mm_P5.00mm
D1: LED; LED_D3.0mm
J1: CONN_02X20; IDC_Header_Straight_40pins
J2: Device power; Pin_Header_Angled_1x04_Pitch2.54mm
J4: CONN_01X39; Pin_Header_Angled_1x39_Pitch2.54mm
R1: 330; R_Axial_DIN0207_L6.3mm_D2.5mm_P10.16mm_Horizontal
R2, R3, R4: 1k; R_Axial_DIN0207_L6.3mm_D2.5mm_P10.16mm_Horizontal
U1: 74LS138; DIP-16_W7.62mm_Socket
U2: 74HCT32N; DIP-14_W7.62mm_Socket

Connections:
/IORD: J1.25, U2.6 (O)
/IOWR: J1.23, U2.3 (O)
A0: J1.35, J4.16
A1: J1.33, J4.15
A2: J1.36, J4.14
A3: J4.13, U1.1 (A0)
A4: J4.12, U1.2 (A1)
A5: J4.11, U1.3 (A2)
A6: J4.10, U1.5 (E2)
BUSY: D1.1 (K), J1.39
D0: J1.17, J4.27
D1: J1.15, J4.28
D2: J1.13, J4.29
D3: J1.11, J4.30
D4: J1.9, J4.31
D5: J1.7, J4.32
D6: J1.5, J4.33
D7: J1.3, J4.34
GND: C1.2, C2.2, J1.2, J1.19, J1.22, J1.24, J1.26, J1.30, J1.40, J2.2, J2.3, J4.17, U1.8 (GND), U2.7 (GND), U2.9 (I0), U2.10 (I1), U2.12 (I0), U2.13 (I1)
IOREQ: J4.26, U1.4 (E1), U2.2 (I1), U2.4 (I0)
M1: J4.19, U1.6 (E3)
unnamed: D1.2 (A), R1.1
unnamed: J1.29, R2.1
unnamed: J1.34, R3.2
unnamed: J1.38, R4.2
PORT16: J1.37, U1.13 (O2)
RD: J4.25, U2.5 (I1)
RESET: J1.1, J4.20
VCC: C1.1, C2.1, J1.20, J2.4, J4.18, R1.2, R2.2, R3.1, R4.1, U1.16 (VCC), U2.14 (VCC)
WR: J4.24, U2.1 (I0)

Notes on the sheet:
RC2014 IDE
CS1
CS0
PDIAG
DMACK
RED
DMARQ

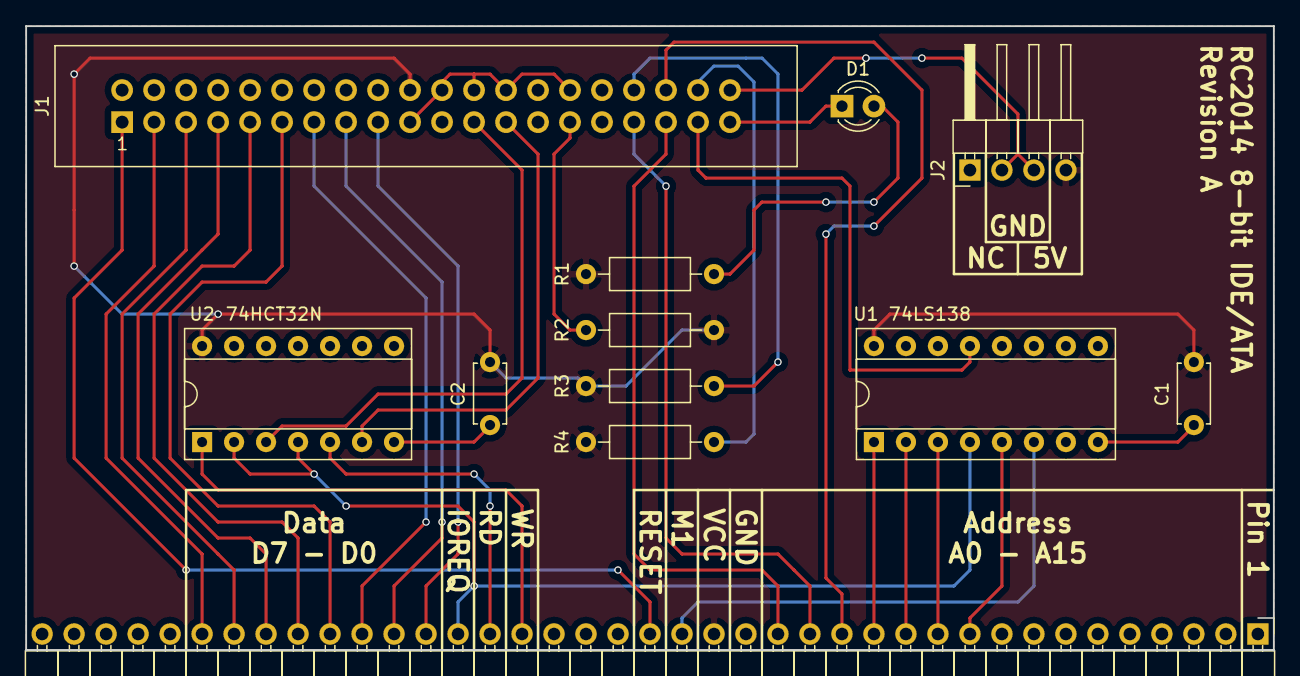
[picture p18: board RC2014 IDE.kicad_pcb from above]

Board: 2 copper layers, 99.1 x 49.5 mm, 12 parts (0 on the bottom side), 30 nets.

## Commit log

2017-05-13 Added IDE Compact Flash Card
    [RC2014 IDE.kicad_pcb, RC2014 IDE.sch]
2017-05-13 Added custom pageable RAM module
    [RC2014 RAM.kicad_pcb, RC2014 RAM.sch]
2017-05-13 Fixed typo
    [RC2014 RAM.kicad_pcb, RC2014 RAM.sch]
2017-05-13 Added RAM pcb
2017-05-13 Added IDE readme with BOM
2017-05-13 Added readme schematic note
2017-05-13 Added RC2014 Tandy Sound Card
    [RC2014 Tandy Sound Card.kicad_pcb, RC2014 Tandy Sound Card.sch]
2017-05-13 Added TDA7065A audio amplification
    [RC2014 Tandy Sound Card.kicad_pcb, RC2014 Tandy Sound Card.sch]
2017-05-14 Added OR-gates to R/W signals
    Seems other people have been having problems when using RD and WR directly, so adding the OR-gates just in case I need them and can't afford to remake the PCBs.
    [RC2014 IDE.kicad_pcb, RC2014 IDE.sch]
2017-05-15 Renumbered ICs to be consistent
    [RC2014 IDE.kicad_pcb, RC2014 IDE.sch]
2017-05-15 Exported files
    [RC2014 IDE-B.Cu.gbl, RC2014 IDE-B.Mask.gbs, RC2014 IDE-B.Paste.gbp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]
2017-05-15 Added pinheaders for selecting address
    [RC2014 Tandy Sound Card.kicad_pcb, RC2014 Tandy Sound Card.sch]
2017-05-19 Added RC2014 Tandy Sound Card pcb preview and plotted the schematic.
2017-06-11 Added volume control
    [RC2014 Tandy Sound Card.sch]
2017-06-13 Tandy Sound card revision A
    PCB layout done including silkscreen. Includes TDA7056A mono amplifier circuit.
    [RC2014 Tandy Sound Card-B.Cu.gbl, RC2014 Tandy Sound Card-B.Mask.gbs, RC2014 Tandy Sound Card-B.Paste.gbp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]
2017-06-13 Updated README.
    [RC2014 RAM-B.Cu.gbl, RC2014 RAM-B.Mask.gbs, RC2014 RAM-B.Paste.gbp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]
2017-06-13 Fixed RAM README pcb url.
2017-06-13 Added Tandy Sound Card BOM.
2017-06-15 Tandy sound card exports.
    [RC2014 Tandy Sound Card-B.Cu.gbl, RC2014 Tandy Sound Card-B.Mask.gbs, RC2014 Tandy Sound Card-B.Paste.gbp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]
